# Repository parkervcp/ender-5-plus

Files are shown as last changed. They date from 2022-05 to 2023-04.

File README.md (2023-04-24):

# parkers ender-5-plus setup

This is my heavily modified ender 5 plus setup. I am also storing models here for things that I have designed for the ender 5 first.

I have listed out all the parts and software changes I have made to the printer as well.

I am still working on moving the runout sensor to right above the hotend so I get more feed before running out, as I am trying to cut back on potential waste.

## Firmware
### Klipper
[kilpper configs](/klipper/)

## Hardware
### Base Hardware
* Ender 5 Plus: https://www.creality3dofficial.com/products/creality-ender-5-plus-3d-printer
* Creality Large Enclosure: https://www.creality3dofficial.com/products/large-3d-printer-enclosure

### Replacement Parts
#### Control Hardware
* Mainboard: https://www.biqu.equipment/products/bigtreetech-skr-2
    * Better controllability and quieter operation.
* Touchscreen: https://www.biqu.equipment/products/btt-tft35-e3-v3-0-display-touch-screen-two-working-modes
    * Stock screen isn't compatible with the skr 2
    * [3d printed mount by jingerale79](https://www.thingiverse.com/thing:4507896)

#### Hotend Hardware
* Extruder/Hotend: https://e3d-online.com/products/revo-hemera
    * Better extruder with the revo hotend for easy nozzle swapping.
* Custom X-Axis carriage
    * [using bltouch](models/x-axis/hemera-linear-mount.stl)
    * using nozzle as probe
        * [linear mount](models/x-axis/hemera-linear-mount-nozzle-probe.stl)
        * [hemera mount](models/x-axis/hemera-mount-nozzle-probe.stl)
* Part Cooling
    * Rene Jurack's hemera cooler seen here - https://rene-jurack.de/well-engineered-hemera-fan-duct-2/
        * the 4010 version needs to special mounts.
        * ebmpapst 5015 blower with bltouch [mount](models/fan-mounts/hemera-bl-touch-5015-mount.stl)
        * ebmpapst 5015 blower for nozzle probe [mount](models/fan-mounts/hemera-5015-mount.stl)

#### Bed Hardware
* Bed: https://preciseprinterparts.com/creality-ender-5-plus--cast-printer-bed.html
    * Flatter base
* Bed Levelling Standoffs: https://smile.amazon.com/gp/product/B07RZKF8MB
    * More solid standoff
* Heater: https://keenovo.store/collections/custom-keenovo-silicone-heaters/products/keenovo-silicone-heater-370mm-x-375mm-for-ender-5-plus-3d-printer-build-plate-heatbed-heat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
    * Better heater for the new bed
* Heater SSR: https://keenovo.store/collections/accessories/products/delixi-ssr-40a480vac-solid-state-relay-input-3v-32vdc-40da
    * Controls the heater
* Mag Base: https://www.th3dstudio.com/product/ezflex-magnetic-base/?attribute_size=376x370mm
    * Easier to swap out beds
* Smooth Plate: https://www.th3dstudio.com/product/ezflex2-flex-plate-smooth-or-textured-pei-coating/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
* Textured Plate: https://www.matterhackers.com/store/l/layerlock-powder-coated-pei-build-plate-steel-sheet/sk/M92RDWH7

#### Motion Hardware
* Linear Rails: 3x450mm MGN12 Linear Rails https://smile.amazon.com/gp/product/B08JYC1XFK
* POM Z-axis Nuts: https://smile.amazon.com/gp/product/B08JQ65PTT
    * Quieter operation
* Drag chain - 10X20mm [Amazon Link](https://www.amazon.com/gp/product/B07SFFT1K5)
    * [drag chain mounts](models/y-axis/dragchain/)
* Custom Y-Axis carriages  
    I have gotten these cut out of aluminum to handle the heat for the chamber and stepper motor.
    * [stepper side](models/y-axis/y-axis-linear-carriage-stepper-side.stl)
        There is an issue with the stepper potentially getting hot and warping the carriage
    * [pulley side](models/y-axis/y-axis-linear-carriage-pully-side.stl)

#### Lighting
* LED channel: https://smile.amazon.com/gp/product/B078J143MN
* LEDs: https://smile.amazon.com/gp/product/B07KYP4Z3H

## 3D Printed part models
### Hotend
* BL/CR Touch mount: [bltouch mount](models/hemera-bltouch-mount.stl)
* Cooling fan duct: https://rene-jurack.de/well-engineered-hemera-fan-duct-2/
    * ebmpapst 5015 blower with bltouch [mount](models/fan-mounts/hemera-bl-touch-5015-mount.stl)
    * ebmpapst 5015 blower for nozzle probe [mount](models/fan-mounts/hemera-5015-mount.stl)

### X-Carriage
I have moved the filament runout sensor to the extruder end as well. Still working on how to handle the boden
* [linear rail mount](models/x-axis/hemera-linear-mount.stl)
* Nozzle as proble
    * [linear mount](models/x-axis/hemera-linear-mount-nozzle-probe.stl)
    * [hemera mount](models/x-axis/hemera-mount-nozzle-probe.stl)

### Y-Carriages  
I have gotten these cut out of aluminum to handle the heat for the chamber and stepper motor.
* [Stepper Side Linear Rail Adapter](models/y-axis/y-axis-linear-carriage-stepper-side.stl)
* [Tensionor Side Linear Rail Adapter](models/y-axis/y-axis-linear-carriage-pully-side.stl)

### Enclosure Lighting
Lighting for either the enclosure or printer
* [Enclosure mounting clips](models/creality-enclosure-lighting-mount.stl)
* [2020 Mounting Clips]() - In progress

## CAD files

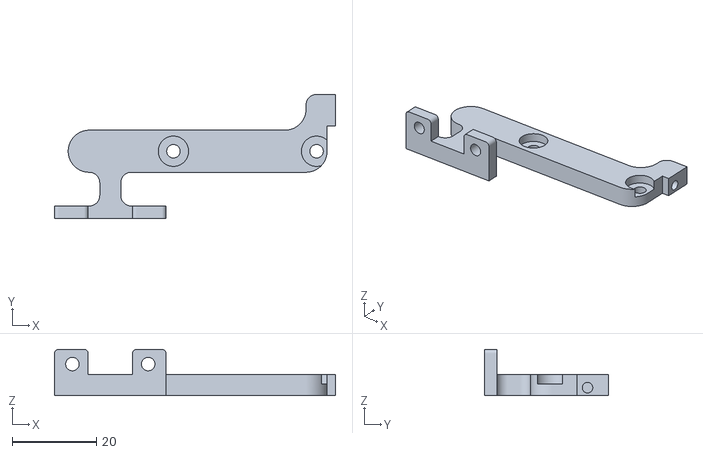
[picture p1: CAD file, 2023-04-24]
models/fan-mounts/hemera-bl-touch-5015-mount.stl
66.8 x 29.5 x 11.0

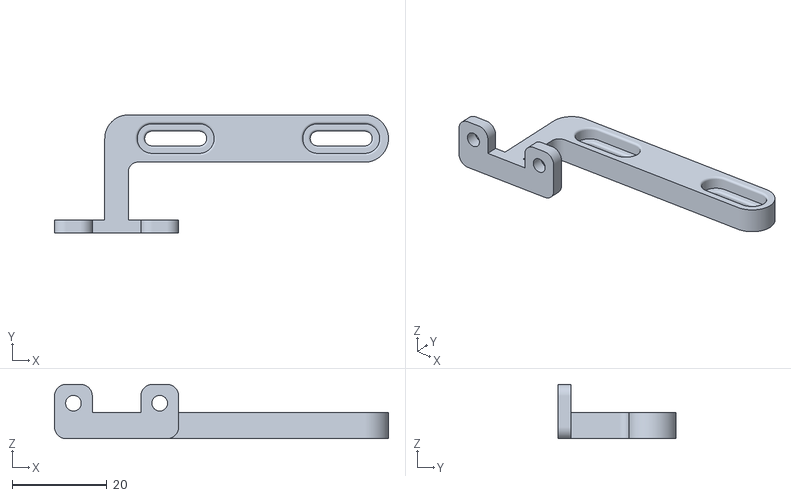
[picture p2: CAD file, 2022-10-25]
models/hemera-bltouch-mount.stl
70.6 x 25.0 x 11.5

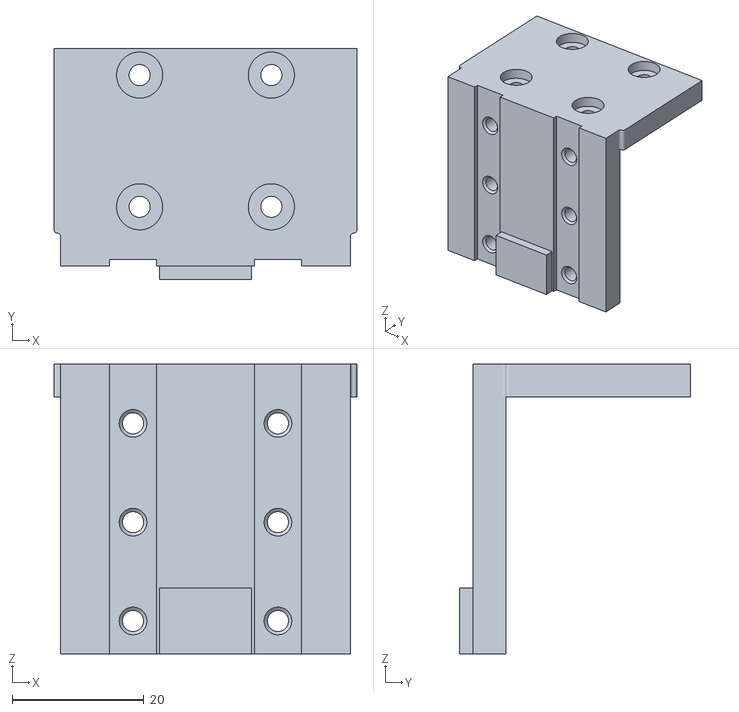
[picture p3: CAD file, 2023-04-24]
models/x-axis/hemera-linear-mount-nozzle-probe.stl
46.0 x 35.0 x 44.0

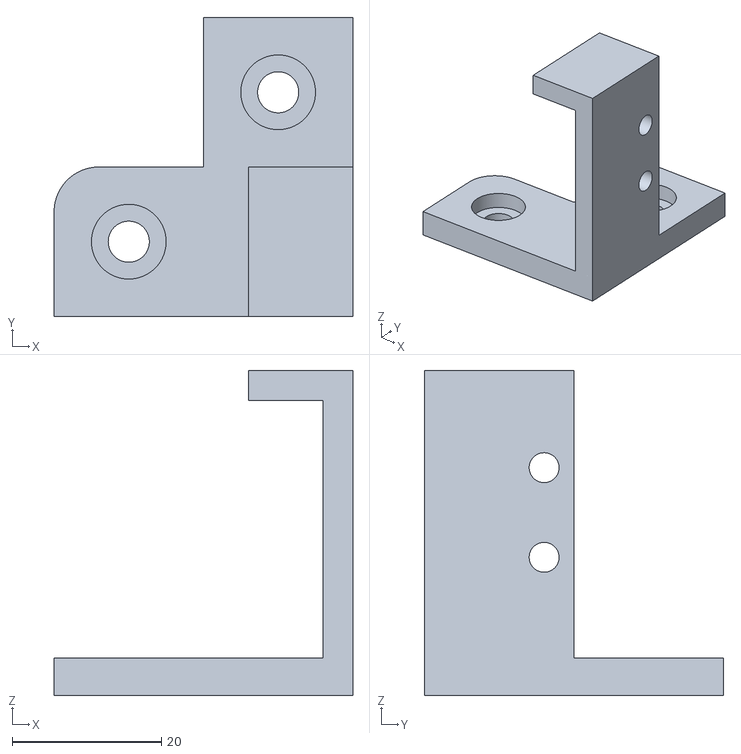
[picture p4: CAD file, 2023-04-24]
models/y-axis/dragchain/y-axis-drag-chain-model.stl
40.0 x 40.0 x 43.5

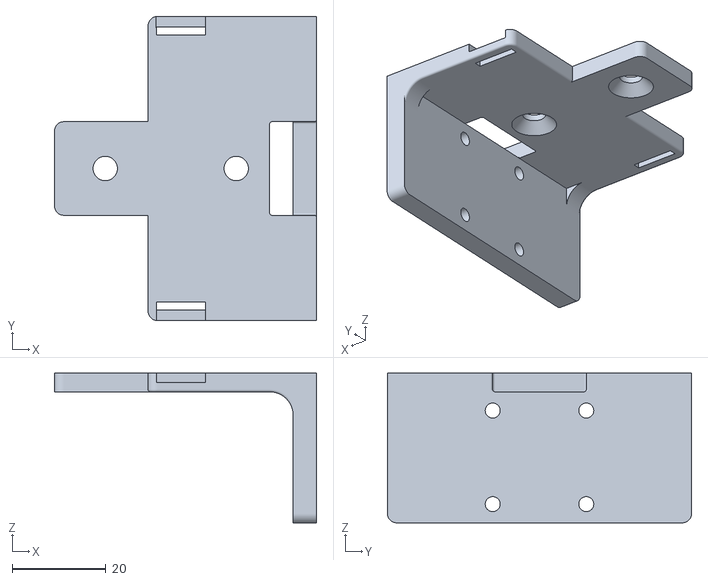
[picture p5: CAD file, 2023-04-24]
models/y-axis/y-axis-linear-carriage-pully-side.stl
56.0 x 65.0 x 32.0

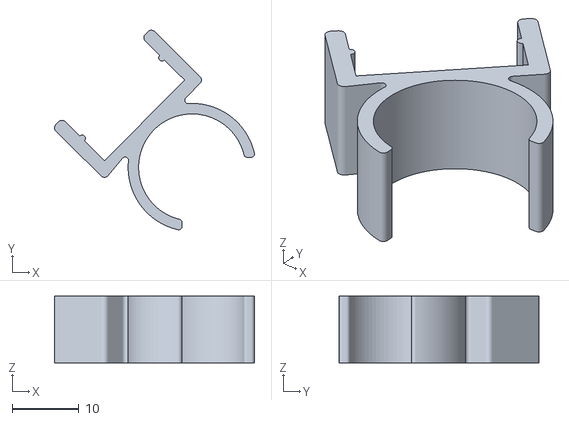
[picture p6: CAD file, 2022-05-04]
models/creality-enclosure-lighting-mount.stl
29.9 x 29.9 x 10.0

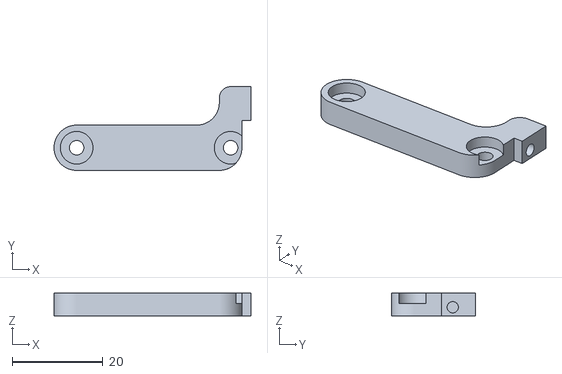
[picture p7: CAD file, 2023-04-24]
models/fan-mounts/hemera-5015-mount.stl
43.5 x 18.5 x 5.00

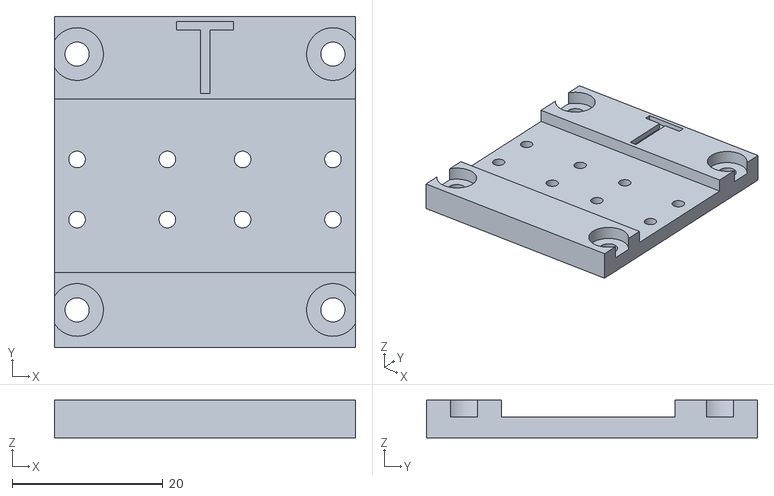
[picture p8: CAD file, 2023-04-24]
models/x-axis/hemera-mount-nozzle-probe.stl
40.0 x 44.0 x 5.00

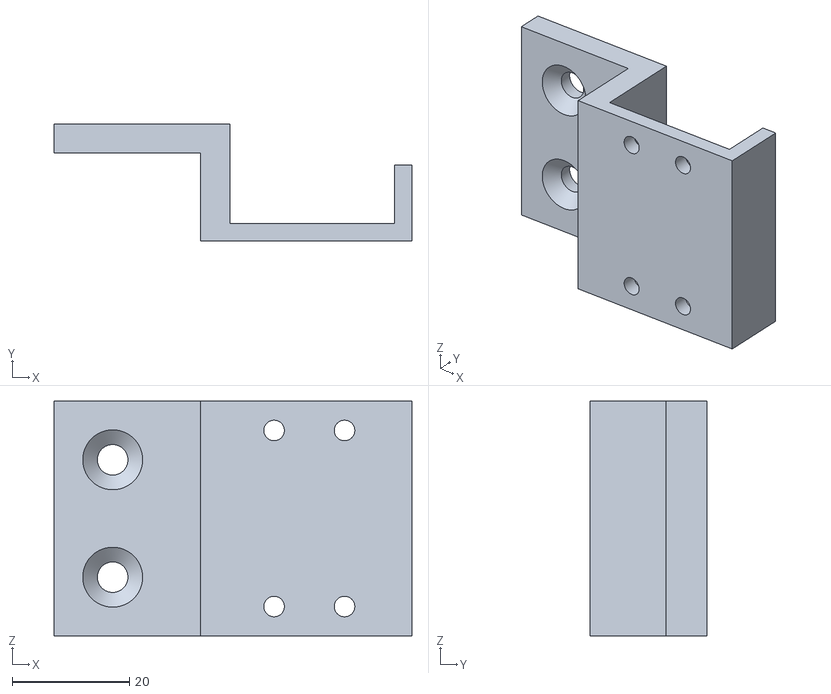
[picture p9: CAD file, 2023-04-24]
models/y-axis/dragchain/y-axis-drag-chain-support.stl
61.0 x 20.0 x 40.0

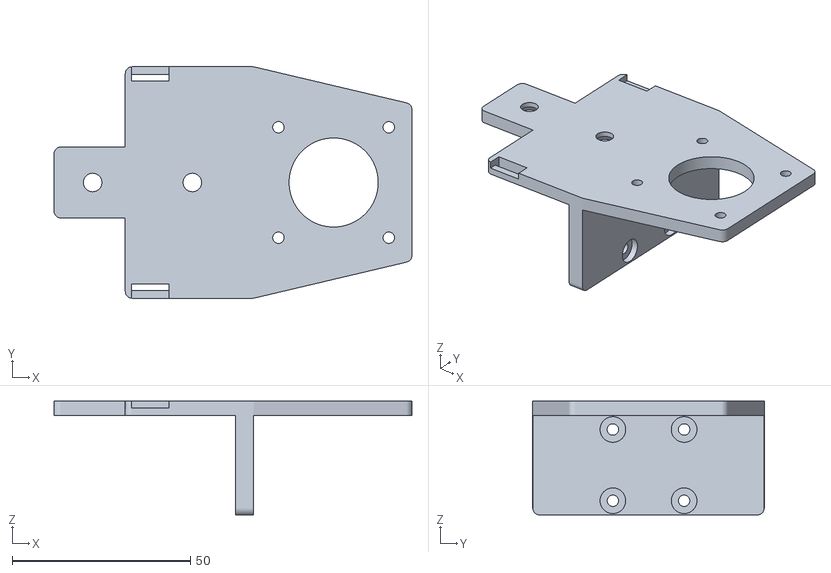
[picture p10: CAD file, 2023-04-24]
models/y-axis/y-axis-linear-carriage-stepper-side.stl
100.5 x 65.0 x 32.0

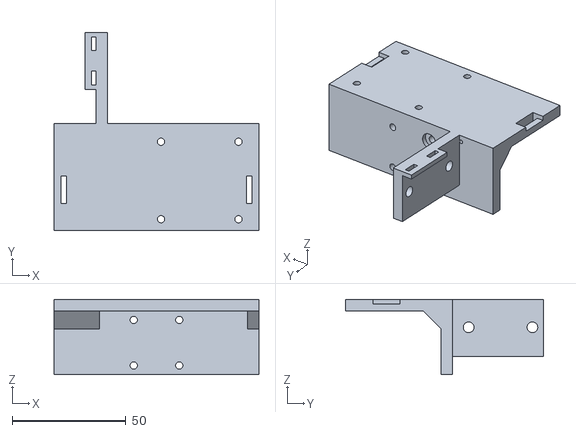
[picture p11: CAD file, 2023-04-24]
models/x-axis/hemera-linear-mount.stl
90.0 x 87.0 x 33.0

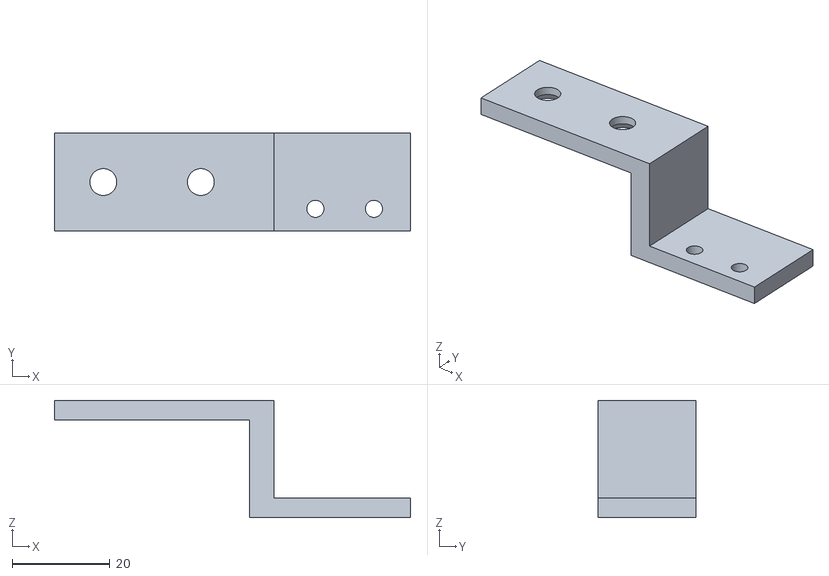
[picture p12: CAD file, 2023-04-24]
models/y-axis/dragchain/y-axix-drag-chain-x-mount.stl
73.0 x 20.0 x 24.0

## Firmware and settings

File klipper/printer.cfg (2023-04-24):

## mixed between the following and custom
## skr 2 https://raw.githubusercontent.com/Klipper3d/klipper/master/config/generic-bigtreetech-skr-2.cfg
## ender 5 plus https://gist.github.com/mihaiserban/bf9aea36454fa2b1e724ab391cce053c
## hemera config https://github.com/Clank50AE/Clanks-Klipper-Configs/blob/master/SideWinder%20X1%20BLTouch%20E3D%20Hemera.cfg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

# -------------
# serial config
# -------------

[mcu]
serial: /dev/ttyACM0

# -------------
# mainsail settings
# -------------

[include mainsail.cfg]

# -------------
# extra settings
# -------------

[exclude_object]

# -------------
# enclosure lighting
# -------------

[neopixel enclosure_lighting]
pin: PE6
chain_count:56
color_order: GRBW
initial_RED: 0.0
initial_GREEN: 0.0
initial_BLUE: 0.0
initial_WHITE: 1.0

# -------------
# Macros
# -------------

[gcode_arcs]

[filament_switch_sensor RUNOUT_SENSOR]
switch_pin: PC2
pause_on_runout: true
runout_gcode:
  M600 #calls a macro with the name M600 (so it can be called by slicers too)
insert_gcode:
  M117 Filament inserted #just a throwaway GCode command to have something in this space. You can add your own.
#   A list of G-Code commands to execute after a filament insert is
#   detected. See docs/Command_Templates.md for G-Code format. The
#   default is not to run any G-Code commands, which disables insert
#   detection.
event_delay: 3.0
pause_delay: 0.0001

[gcode_macro G29]
gcode: 
  G28
  BED_MESH_CALIBRATE
  BED_MESH_PROFILE SAVE=preflight
  G1 X0 Y0 Z5 F4000


[gcode_macro M600]
gcode:
    {% set X = params.X|default(50)|float %}
    {% set Y = params.Y|default(0)|float %}
    {% set Z = params.Z|default(50)|float %}
    #SAVE_GCODE_STATE NAME=M600_state
    SET_IDLE_TIMEOUT TIMEOUT=30000
    PAUSE
    G91
    G1 E-5 F2700
    G1 Z{Z}
    #G1 E-100 F5000
    G90
    G1 X{X} Y{Y} F3000
    #G91

# -------------
# motion system
# -------------

[printer]
kinematics: cartesian
max_velocity: 300
max_accel: 6000
max_z_velocity: 5
max_z_accel: 100
square_corner_velocity: 20

[stepper_x]
dir_pin: !PE1
step_pin: PE2
enable_pin: !PE3
endstop_pin: ^PC1
rotation_distance: 40.035 # pitch 2mm, teeth 20
# full_steps_per_rotation: 200
microsteps: 16
homing_speed: 50
position_min: 0
position_max: 355
position_endstop: 355

[tmc2209 stepper_x]
uart_pin: PE0
run_current: 0.8
# stealthchop_threshold: 999999

[stepper_y]
dir_pin: !PD4
step_pin: PD5
enable_pin: !PD6
endstop_pin: ^PC3
homing_retract_dist: 0
rotation_distance: 39.82 # pitch 2mm, teeth 20?
# full_steps_per_rotatin: 200
microsteps: 16
homing_retract_dist: 0
homing_speed: 50
position_min: 0
position_max: 360
position_endstop: 360

[tmc2209 stepper_y]
uart_pin: PD3
run_current: 0.8
# stealthchop_threshold: 999999

[stepper_z]
dir_pin: !PA8
step_pin: PA15
enable_pin: !PD1
endstop_pin: probe:z_virtual_endstop
rotation_distance: 3.993 # pitch 2mm, threads 2
# full_steps_per_rotation: 200
microsteps: 16
position_min: -5
position_max: 400

[tmc2209 stepper_z]
uart_pin: PD0
run_current: 0.8
# stealthchop_threshold: 999999

[stepper_z1]
dir_pin: !PD10
step_pin: PD11
enable_pin: !PD13
endstop_pin: probe:z_virtual_endstop
rotation_distance: 3.991 # pitch 2mm, threads 2
# full_steps_per_rotation: 200
microsteps: 16

[tmc2209 stepper_z1]
uart_pin: PD12
run_current: 0.8
# stealthchop_threshold: 999999

# -------------
# bed level
# -------------

[bltouch]
sensor_pin: ^PE4
control_pin: PE5
stow_on_each_sample: false
probe_with_touch_mode: true
pin_up_touch_mode_reports_triggered: false
speed: 100
lift_speed: 200
samples: 2
sample_retract_dist: 10
samples_tolerance_retries: 4
x_offset: 0
y_offset: -35
#z_offset: 5.12

[safe_z_home]
speed: 100
z_hop: 10
z_hop_speed: 10
home_xy_position: 175,210

[bed_mesh]
speed: 100
horizontal_move_z: 10
probe_count: 5,5
algorithm: bicubic
mesh_min: 50,50
mesh_max: 300,300

[screws_tilt_adjust]
screw1: 33,70
screw1_name: front left screw
screw2: 330,70
screw2_name: front right screw
screw3: 330,340
screw3_name: rear right screw
screw4: 33,340
screw4_name: rear left screw
horizontal_move_z: 10.
speed: 1500
screw_thread: CW-M4

# -------------
# hot bits
# -------------

[extruder]
dir_pin: PD14
step_pin: PD15
enable_pin: !PC7
microsteps: 16
rotation_distance: 8.159
## hotend
filament_diameter: 1.750
nozzle_diameter: 0.800
heater_pin: PB3
sensor_type: ATC Semitec 104NT-4-R025H42G
sensor_pin: PA2
#control: pid
#pid_Kp=29.104
#pid_Ki=2.487
#pid_Kd=85.128
min_temp: 0
max_temp: 275
# for extruder calibration
min_extrude_temp: 0
pressure_advance: 0.035

[tmc2209 extruder]
uart_pin: PC6
run_current: 0.845
# stealthchop_threshold: 999999


[heater_bed]
heater_pin: PD7
sensor_type: EPCOS 100K B57560G104F # Creality bed thermistor
sensor_pin: PA1
#control: pid
#pid_kp = 59.679
#pid_ki = 0.681
#pid_kd = 1306.979
min_temp: 0
max_temp: 130

# -------------
# cold bits
# -------------

# fan 0
[fan]
pin: PB7

# fan 1
[heater_fan hotend_fan]
pin: PB6
heater: extruder
heater_temp: 50.0

# fan 2
[controller_fan board_cooling_fan]
pin: PB5

# Due to BTT implementing a Marlin-specific safety feature,
# "anti-reversal stepper protection", this pin needs pulling
# high to pass power to stepper drivers and most FETs

[output_pin motor_power]
pin: PC13
value: 1

# -------------
# display config
# -------------

########################################
# EXP1 / EXP2 (display) pins
########################################

[board_pins]
aliases:
    # EXP1 header
    EXP1_1=PC5, EXP1_3=PB1, EXP1_5=PE10, EXP1_7=PE12, EXP1_9=<GND>,
    EXP1_2=PB0, EXP1_4=PE9, EXP1_6=PE11, EXP1_8=PE13, EXP1_10=<5V>,
    # EXP2 header
    EXP2_1=PA6, EXP2_3=PE7, EXP2_5=PB2, EXP2_7=PC4,   EXP2_9=<GND>,
    EXP2_2=PA5, EXP2_4=PA4, EXP2_6=PA7, EXP2_8=<RST>, EXP2_10=<NC>

# See the sample-lcd.cfg file for definitions of common LCD displays.

[display]
lcd_type: st7920
cs_pin: EXP1_4
sclk_pin: EXP1_5
sid_pin: EXP1_3
encoder_pins: ^EXP2_3, ^EXP2_5
click_pin: ^!EXP1_2
#kill_pin: ^!EXP2_8

[output_pin beeper]
pin: EXP1_1

#*# <---------------------- SAVE_CONFIG ---------------------->
#*# DO NOT EDIT THIS BLOCK OR BELOW. The contents are auto-generated.
#*#
#*# [extruder]
#*# control = pid
#*# pid_kp = 29.104
#*# pid_ki = 2.487
#*# pid_kd = 85.128
#*#
#*# [heater_bed]
#*# control = pid
#*# pid_kp = 59.679
#*# pid_ki = 0.681
#*# pid_kd = 1306.979
#*#
#*# [bed_mesh default]
#*# version = 1
#*# points =
#*# 	  0.016845, -0.011230, 0.010606, 0.000000, 0.011854
#*# 	  0.057399, 0.019341, 0.034315, 0.009359, 0.021213
#*# 	  0.061143, 0.021213, 0.017469, -0.002496, -0.009982
#*# 	  0.063015, 0.001872, 0.020589, 0.008111, 0.008735
#*# 	  0.038058, -0.024956, -0.001872, 0.000000, 0.006863
#*# x_count = 5
#*# y_count = 5
#*# mesh_x_pps = 2
#*# mesh_y_pps = 2
#*# algo = lagrange
#*# tension = 0.2
#*# min_x = 50.0
#*# max_x = 300.0
#*# min_y = 50.0
#*# max_y = 300.0
#*#
#*# [bltouch]
#*# z_offset = 1.237
#*#
#*# [bed_mesh preflight]
#*# version = 1
#*# points =
#*# 	-0.062141, -0.042256, 0.019264, 0.003728, -0.022371
#*# 	0.042256, 0.055927, 0.087618, 0.055305, 0.004350
#*# 	0.041013, 0.058412, 0.095697, 0.055305, 0.009942
#*# 	0.059655, 0.081404, 0.113096, 0.082026, 0.031070
#*# 	0.013050, 0.011185, 0.062762, 0.054062, 0.000621
#*# x_count = 5
#*# y_count = 5
#*# mesh_x_pps = 2
#*# mesh_y_pps = 2
#*# algo = bicubic
#*# tension = 0.2
#*# min_x = 50.0
#*# max_x = 300.0
#*# min_y = 50.0
#*# max_y = 300.0

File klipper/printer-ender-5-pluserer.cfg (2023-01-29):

## mixed between the following and custom
## skr 2 https://raw.githubusercontent.com/Klipper3d/klipper/master/config/generic-bigtreetech-skr-2.cfg
## ender 5 plus https://gist.github.com/mihaiserban/bf9aea36454fa2b1e724ab391cce053c
## hemera config https://github.com/Clank50AE/Clanks-Klipper-Configs/blob/master/SideWinder%20X1%20BLTouch%20E3D%20Hemera.cfg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


[virtual_sdcard]
path: ~/gcode_files

# -------------
# serial config
# -------------

[mcu]
serial: /dev/serial/by-id/usb-Klipper_Klipper_firmware_12345-if00

# mainsail settings
[include mainsail.cfg]

# display settings
[include display.cfg]

# led settings
[include led.cfg]

# -------------
# motion system
# -------------

[printer]
kinematics: cartesian
max_velocity: 250
max_accel: 6000
max_accel_to_decel: 6000
max_z_velocity: 10
max_z_accel: 100
square_corner_velocity: 20

[tmc2209 stepper_x]
uart_pin: PE0
dir_pin: PE1
step_pin: PE2
enable_pin: !PE3
endstop_pin: ^PC1
run_current: 1.0
microsteps: 16
rotation_distance: 40 # pitch 2mm, teeth 20
full_steps_per_rotation: 200
homing_speed: 50
position_min: 0
position_max: 350
position_endstop: 350

[tmc2209 stepper_y]
uart_pin: PD3
dir_pin: !PD4
step_pin: PD5
enable_pin: !PD6
endstop_pin: ^PC3
homing_retract_dist: 0
run_current: 1.0
microsteps: 16
rotation_distance: 40 # pitch 2mm, teeth 20?
full_steps_per_rotation: 200
homing_speed: 50
position_min: 0
position_max: 350
position_endstop: 350

[tmc2209 stepper_z]
uart_pin: PD0
dir_pin: PA8
step_pin: PA15
enable_pin: !PD1
endstop_pin: probe:z_virtual_endstop
run_current: 1.0
microsteps: 16
rotation_distance: 4 # pitch 2mm, threads 2
full_steps_per_rotation: 200
position_min: -5
position_max: 400

[tmc2209 stepper_z1]
uart_pin: PD12
dir_pin: PD10
step_pin: PD11
enable_pin: !PD13
endstop_pin: probe:z_virtual_endstop
run_current: 1.0
microsteps: 16
rotation_distance: 40
rotation_distance: 4 # pitch 2mm, threads 2
position_min: -5
position_max: 420

# -------------
# hot bits
# -------------

[tmc2209 extruder]
filament_diameter: 1.750
## stepper
uart_pin: PC6
dir_pin: PD14
step_pin: PD15
enable_pin: !PC7
run_current: 0.845
microsteps: 16
rotation_distance: 7.862
stealthchop_threshold: 5
## hotend
nozzle_diameter: 0.400
heater_pin: PB3
sensor_type: ATC Semitec 104NT-4-R025H42G
sensor_pin: PA2
control: pid
pid_kp = 21.465
pid_ki = 0.980
pid_kd = 117.521
min_temp: 0
max_temp: 275
min_extrude_temp: 190

[heater_bed]
heater_pin: PD7
sensor_type: EPCOS 100K B57560G104F # Creality bed thermistor
sensor_pin: PA1
control: pid
pid_kp = 21.465
pid_ki = 0.980
pid_kd = 117.521
min_temp: 0
max_temp: 130

# -------------
# hot bit cooling
# -------------

[fan part_cooling_fan]
pin: PB6

[heater_fan hotend_fan]
pin: PB7
heater: extruder
heater_temp: 50.0

[controller_fan mainboard_fan]
pin: PB5

# Due to BTT implementing a Marlin-specific safety feature,
# "anti-reversal stepper protection", this pin needs pulling
# high to pass power to stepper drivers and most FETs

[output_pin motor_power]
pin: PC13
value: 1

[printer]
kinematics: cartesian
max_velocity: 300
max_accel: 3000
max_z_velocity: 5
max_z_accel: 100

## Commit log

2022-04-25 Add Configuration Files
    [Configuration.h, Configuration_adv.h]
2022-04-26 add Z anti-backlash parts
2022-04-28 Add enclosure lighting
    Add LED channel system
    Add Channel Mounting Clips
    [e5p-enclosure-lighting-mount.stl]
2022-05-04 change out extruder
    Changed to the microswiss until I get my hemera in.
2022-05-04 update extruder settings
    Update E0 current to 1a
    Update E0 steps to 200
    [Configuration.h, Configuration_adv.h]
2022-05-06 Update for leds
    Enable LED Lighting on board.
    Configure LED Type
    Adjust E Steps after calculating them.
    [Configuration.h, Configuration_adv.h]
2022-05-06 Update README
    Update format
    Add Bi-Metal heatbreak.
    Add LEDs
2022-05-06 Update README
    Add Mag Base and Flex Plates
2022-10-25 update models and readme
    Update README for new models and part for carriage backer.
    Add model for Hemera BL Touch Mount
    Add model for Hemera Mount Adapter
    Rename enclosure mount file
    [creality-enclosure-lighting-mount.stl, hemera-bltouch-mount.stl, hemera-e5p-adapter.stl]
2023-01-27 Moving to klipper
    Just moving to klipper from marlin
    [Configuration.h, Configuration_adv.h, printer-ender-5-pluserer.cfg]
2023-01-29 break config into multiple files
    [bltouch.cfg, display.cfg, led.cfg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]
2023-02-11 update klipper configs
    [bltouch.cfg, display.cfg, led.cfg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]
2023-02-11 fix config problems
    [led.cfg, printer.cfg]
2023-02-12 update bltouch config
    update bltouch sensor pin
    update z-offset
    update screw adjust config
    [bltouch.cfg]
2023-02-12 update printer config
    update serial port
    update stepper configs
    add stealthchop
    [printer.cfg]
2023-02-26 fine tune settings
    Calibrate all axis and extruder steppers
    Calibrate bed and nozzle heater pid values
    Correct pin values for fans
    [bltouch.cfg, printer.cfg]
2023-02-26 Add crowsnest config
    Add crowsnest config
    [crowsnest.cfg]
2023-04-24 update stepper configs
    disable stealthchop
    recalibrate rotation distance for all steppers ( will probably happen again for x)
    Z-offset is set by probe_calibration
    [printer.cfg]
2023-04-24 Add New Models
    Adding all current models I have.
    This includes my work in progress nozzle probe mounts.
    Updates readme with all information.
    [hemera-5015-mount.stl, hemera-bl-touch-5015-mount.stl, hemera-e5p-adapter.stl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]
